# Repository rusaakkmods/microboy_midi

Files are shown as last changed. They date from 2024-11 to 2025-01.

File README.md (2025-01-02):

rusaaKKMODS - MicroBOY MIDI
---------------------------
'SPECIAL THANKS TO:'
  - Johan Kotlinski (@johan_kotlinski) for his work on LSDJ.
  - Timothy Lamb (@trash80) for his work on Arduinoboy. It's a great reference for me.
  - Nikita Bogdan (@nikitabogdan) & Alfian (instagram: @alfian_nay93) for briliant PC ideas!
  - AND of course our kooky AI: GPT 4o (ChatGPT, Copilot). Why not!!

 The code is still in the early stage, but it’s working as expected. The Gameboy is sending MIDI messages to the microcontroller, and the microcontroller is routing the messages to the MIDI output. 
 The next step is to add more features to the microcontroller, such as saving the configuration to EEPROM, adding a rotary encoder to change the output channel, and adding a button to change the CC mode and scaling.

  Reading Gameboy Message LSDJ MI.OUT MODE
  ----------------------------------------
  When LSDJ in MI.OUT mode; it is actually the Gameboy being Slave!!.
  In order for LSDJ send data byte, we have to send clock signal bit by bit. 
  Each clock signal send to the Gameboy will also trigger sending 1 bit of data out from Serial Out (SO) line.
  Read: docs/gb_clock.md
  Downside: LSDJ doesn't send Sequencer BPM clock information!

  This project is using Arduino Pro Micro / Leonardo
  --------------------------------------------------
  - I'll add compatibility for other microcontroller later on
  - Serial1 is used for MIDI communication
  - Serial is used for debugging purpose. disable it when not needed
  - CLOCK_PIN is used for Gameboy Clock -- Connect to Gameboy Serial Clock (SC) // it is full duplex may crash the Gameboy/LSDJ
  - SI_PIN is used for Message In (SI) -- Connect to Gameboy Serial Out (SO)
  - SO_PIN is used for Message Out (SO) -- Connect to Gameboy Serial In (SI)
  - By default, LSDJ use channel 1, 2, 3, 4 for each track respectively (PU1, PU2, WAV, NOI)
  
  Microboy Features
  -----------------
  - Sync with LSDJ MI.OUT Mode
  - Utilizing Program Change 127 (Gunshot) | LSDJ Y command FF to trigger Clock!
  - Adjustable Velocity knob
  - BPM calculation
  - Redirect each track to different MIDI channel
  - OLED Display information
  - Rotary Knob Control Setup

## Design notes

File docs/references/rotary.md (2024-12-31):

### Fixing Rotary Encoder Issues: References and Techniques

#### 1. Rotary Encoder Debouncing
**Reference:** [Debouncing Rotary Encoders](https://www.gammon.com.au/forum/?id=14175)

- This tutorial explains hardware and software debounce techniques for rotary encoders.
- Covers RC filters for hardware and software algorithms for filtering noisy transitions.

#### 2. Arduino Encoder Library
**Reference:** [Arduino Encoder Library (GitHub)](https://github.com/PaulStoffregen/Encoder)

- This library efficiently handles quadrature decoding for rotary encoders.
- Works well for both simple and high-speed encoders.
- Handles edge cases like skipped pulses due to fast rotation.

#### 3. Quadrature Decoding Explained
**Reference:** [How Rotary Encoders Work](https://www.pjrc.com/teensy/td_libs_Encoder.html)

- A detailed explanation of quadrature signals and how to decode them accurately.
- Includes information about state transitions and how to avoid invalid states.

#### 4. Noise Filtering Techniques
**Reference:** [Filtering Noisy Signals](https://www.allaboutcircuits.com/technical-articles/debouncing-switches-in-hardware-and-software/)

- Discusses noise filtering using hardware components (RC filters) and software logic.
- Provides insights into creating robust signal filters for noisy environments.

#### 5. Pin Change Interrupts (PCINT)
**Reference:** [Using Pin Change Interrupts](https://www.gammon.com.au/forum/?id=10896)

- Explains how to configure PCINT on AVR-based microcontrollers.
- Demonstrates efficient interrupt handling for signal changes.

### Techniques to Solve Similar Issues

#### 1. **Check Encoder Quality**
- Low-cost encoders may produce unstable signals. Use high-quality brands like **ALPS** or **Bourns** for better results.

#### 2. **State Machine for Quadrature Decoding**
- Implement a state machine to validate transitions and ignore invalid or noisy transitions.

#### 3. **Debounce Delay**
- Use a debounce delay of 5-10 ms depending on the encoder’s rotational speed.

#### 4. **Hardware Noise Filtering**
- Use an **RC filter** for each encoder signal line:
  - Resistor: 10 kΩ
  - Capacitor: 0.1 µF
- This reduces high-frequency noise.

#### 5. **Timer-Based Polling**
- Instead of relying solely on interrupts, use a timer to poll encoder states at a fixed frequency (e.g., every 1 ms).

#### 6. **Oscilloscope Analysis**
- Use an oscilloscope to analyze the encoder signals for noise or irregularities.

#### 7. **Use Encoder Libraries**
- Libraries like `Encoder.h` simplify decoding logic and optimize performance for high-speed rotations.

#### 8. **Combine Hardware and Software Filters**
- Use a combination of hardware (RC filter) and software debounce or noise filtering algorithms.

#### 9. **Optimize ISR**
- Ensure the Interrupt Service Routine (ISR) is short and efficient. Delegate heavy processing to the main loop.

### Example Solution with Encoder Library and PCINT
- Use the **Encoder** library for accurate quadrature decoding.
- Enable PCINT for additional functionality like buttons or other input monitoring.

#### Sample Code:
```cpp
#include <Encoder.h>
#include <avr/interrupt.h>

// Pin definitions
#define ENCODER_PIN_A 8
#define ENCODER_PIN_B 9
#define BUTTON_PIN 7

Encoder myEnc(ENCODER_PIN_A, ENCODER_PIN_B);
volatile bool buttonPressed = false;

ISR(PCINT0_vect) {
  if (digitalRead(BUTTON_PIN) == LOW) {
    buttonPressed = true;
  } else {
    buttonPressed = false;
  }
}

void setup() {
  pinMode(ENCODER_PIN_A, INPUT_PULLUP);
  pinMode(ENCODER_PIN_B, INPUT_PULLUP);
  pinMode(BUTTON_PIN, INPUT_PULLUP);

  PCICR |= (1 << PCIE0); // Enable PCINT for group 0
  PCMSK0 |= (1 << PCINT7); // Enable PCINT for BUTTON_PIN
  sei(); // Enable global interrupts
}

void loop() {
  long position = myEnc.read();
  if (buttonPressed) {
    // Handle button press
  }
  // Handle encoder position changes
}
```

By following these references and implementing the suggested techniques, you can fix most issues with rotary encoder noise, missed steps, and jitter.

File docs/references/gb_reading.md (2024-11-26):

### Improving Game Boy DMG Link Transmission

Improving the **Game Boy DMG** link transmission stability can help ensure more reliable data exchange, especially if you're experiencing **noise**, **missed bits**, or **unsynchronized communication**. Here are several strategies to improve the quality and reliability of the **link transmission** between Game Boy DMG units or between a Game Boy and another device like an Arduino:

#### 1. Use Pull-Up Resistors and Debouncing Capacitors
- The **Serial In (SI)** and **Serial Out (SO)** lines should be pulled **HIGH** by default to avoid floating, which can lead to **noise** and incorrect data readings.
- Adding **external pull-up resistors** of about **10kΩ** to **5V** on both the **SI** and **SO** pins can help keep the lines stable when no active data is being transmitted. To do this:

- Connect one end of a **10kΩ resistor** to **5V**.
- Connect the other end to the **SI** or **SO** line.
- Repeat this for both the **SI** and **SO** pins to ensure they are pulled HIGH when idle.

This will help stabilize the communication lines and avoid floating states.
- Even if internal pull-ups are used, adding **external pull-ups** may help ensure stronger and more consistent signal levels.

#### 2. Reduce Cable Length and Use Shielded Cables
- **Long cables** can lead to **signal degradation** and **cross-talk**, which can increase the likelihood of errors in the transmission.
- **Shorten the link cable** as much as possible, or use a cable with **shielded wiring** to minimize **electrical interference**.
- If the Game Boy link cable is being extended, ensure it’s done with properly shielded wires to avoid picking up **EMI (Electromagnetic Interference)**.

#### 3. Improve Clock Signal Quality
- The **Serial Clock (SC)** signal quality is crucial to ensure both the **master** and **slave** Game Boys stay synchronized.
- Ensure that the clock signal generated by the master is clean, with no **jitter** or **glitches**.
- To achieve this:
  - **Use capacitors** (e.g., **100 nF** ceramic capacitors) between the **SC line** and **ground** to filter out high-frequency noise.
  - If you are generating the clock from an Arduino or other microcontroller, experiment with adjusting the **timing** (e.g., slightly increasing or decreasing the delays) to find the most stable transmission speed.

#### 4. Stabilize Power Supply
- A **stable power supply** is essential for reliable communication.
- Ensure that your Game Boy DMG is powered by **fresh batteries** or a reliable **regulated power supply**.
- If using batteries, **fresh alkaline batteries** are better for maintaining consistent voltage. Rechargeable batteries can sometimes introduce **voltage drops** that may lead to communication errors.

#### 5. Debounce the Clock and Data Lines with Capacitors
- Electrical noise or bouncing signals can cause erroneous triggering of the data lines.
- **Debouncing** the **clock and data lines** can be achieved by:

- **Adding capacitors**: Connect a **small ceramic capacitor** (e.g., **10 nF to 100 nF**) between each data line (**SI** and **SO**) and **ground**. This helps filter out any spikes or noise on these lines and stabilizes the signal.
  - For the **clock line (SC)**, add a **100 nF capacitor** between the clock line and ground to reduce jitter and noise.
  - Ensure the capacitors are physically close to the Game Boy link port to minimize interference.
  - Adding a **small capacitor** (e.g., **10 nF to 100 nF**) between the clock line and ground to filter out any spikes or noise.
  - In software, adding a **small delay** after each clock pulse can help stabilize the signal.

#### 6. Minimize Crosstalk Between Lines
- In the **Game Boy link cable**, **crosstalk** between the **clock**, **SI**, and **SO** lines can introduce unwanted signals.
- Keeping the **clock line** separate from the **data lines** in the cable can help reduce crosstalk.
- Use **twisted pair wiring** for data and ground, and a separate shielded wire for the clock line.

#### 7. Proper Grounding
- Ensure that both Game Boys share a **common ground** through the link cable.
- A poor or inconsistent ground connection can lead to differences in voltage levels between the devices, resulting in errors.
- Verify that all ground connections in the link cable are properly connected and that there is minimal resistance between them.

#### 8. Check for Consistent Timing
- The **master Game Boy** controls the pace of data transfer through the **clock pulses**.
- Ensure that the **clock timing** is consistent, especially if using a custom device (e.g., Arduino) to generate the clock.
- Use an **oscilloscope** to monitor the clock and data signals:
  - Check that the **clock pulse width** is consistent.
  - Verify that each bit is being read correctly by the master in sync with the clock transitions.

#### 9. Adjust Master Clock Speed
- The typical **link clock speed** for the Game Boy DMG is **8 kHz**, but small variations may help in improving reliability.
- Experiment with slightly different clock frequencies (e.g., **7.5 kHz to 8.5 kHz**) to find the most stable communication speed for your specific hardware.

#### 10. Improve Data Protocol Handling in Software
- The Game Boy link transmission depends heavily on the **game software** for handling data correctly.
- Ensure that your code is capable of:
  - **Retrying data transmission** if an error is detected.
  - Using **handshaking** techniques to ensure both devices are ready for communication.
- Some games use a **checksum** or other verification mechanism to validate data integrity. Implementing similar methods can help detect and correct errors.

### Key Adjustments:
- **Pull-Up Resistors**: Use **`INPUT_PULLUP`** to keep the **SI** and **SO** pins stable.
- **Delays**: Carefully adjusted **delayMicroseconds()** values to stabilize the clock and data lines.

By addressing these hardware and timing factors, you can significantly improve the reliability of the Game Boy DMG link communication and reduce the likelihood of errors during data transmission.

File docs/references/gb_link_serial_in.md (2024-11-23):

### Should the Slave's Serial In (SI) Pin Be HIGH by Default?

Yes, the **slave's Serial In (SI)** pin should be **HIGH by default**. This is a common requirement for **synchronous serial communication** in the Game Boy link protocol. Here's why:

#### Why the Serial In (SI) Pin Should Be HIGH by Default

1. **Idle State Requirement**:
   - In the Game Boy link communication protocol, the **Serial In (SI)** pin, which is used by the **slave** to receive data, is typically set to **HIGH** during the **idle state**.
   - This idle HIGH state ensures that there is no unintended signal or noise interpreted as valid data when the link is not actively being used.

2. **Avoiding False Triggers**:
   - If the **SI** line were **floating** or left **LOW** by default, noise could be interpreted as incoming bits, which would lead to incorrect data being received or communication errors.
   - Pulling the **SI** line HIGH ensures that any actual communication starts with a clear signal when the **master** sends data.

3. **Pull-Up Resistors**:
   - To ensure that the **SI** line is HIGH by default, a **pull-up resistor** is used. In the Game Boy hardware and typical link cable circuits, there may be internal or external pull-up resistors on the **SI** line.
   - In a setup involving an Arduino or another microcontroller, you can enable an **internal pull-up resistor** to ensure the **SI** pin stays HIGH unless actively driven LOW by the master.

4. **Consistent Communication**:
   - The Game Boy link protocol expects consistent signal levels. Having the **SI** line HIGH by default helps both the **master** and **slave** remain synchronized, and ensures that the **slave** only reacts to deliberate signals from the master.

#### How to Set the SI Pin HIGH by Default

If you're using an Arduino to simulate the **master** or **slave** in the link communication, you can set the **SI** pin HIGH by enabling an internal pull-up resistor:

```cpp
pinMode(SI_PIN, INPUT_PULLUP);
```

- **`INPUT_PULLUP`** mode will connect an internal **pull-up resistor** to the **SI** pin, ensuring it stays **HIGH** unless pulled LOW by the master device.

#### Summary
- The **slave's Serial In (SI)** pin should be **HIGH** by default when idle.
- This is achieved by using a **pull-up resistor** to avoid noise or unintended signals that could be misinterpreted.
- Setting the **SI** line HIGH by default ensures clean and reliable communication, which is critical for the **synchronous** Game Boy link protocol.

This default HIGH state helps maintain stability in the communication protocol, allowing both devices to recognize valid data transmission more effectively.

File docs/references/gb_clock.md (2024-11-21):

### Game Boy Clock Rate Explained

The **Game Boy clock rate** refers to the frequency of the **Serial Clock (SC)** signal on the Game Boy link port, which is used to synchronize data transfer between two devices (e.g., two Game Boys or a Game Boy and another device).

#### Game Boy Serial Clock Rate

1. **Purpose of Serial Clock (SC)**:
   - The **Serial Clock (SC)** is a signal generated by the **master device** (usually one Game Boy in the link setup).
   - It synchronizes the transfer of data bits between the devices connected via the link port.

2. **Clock Frequency**:
   - The clock operates at approximately **8 KHz** (8000 cycles per second).
   - This means each clock pulse lasts around **125 microseconds** (1 / 8000 = 0.000125 seconds).

3. **Data Rate**:
   - The data is transferred **synchronously** with the clock, meaning that:
     - 1 bit is sent per clock cycle.
     - The **bit rate** is the same as the clock frequency: **8 Kbps (kilobits per second)**.
   - Since data is transmitted in bytes (8 bits), the effective **byte rate** is approximately:
     - **1000 bytes per second** (8000 bits ÷ 8 = 1000 bytes).

#### Timing of Clock Pulses

1. **Idle State**:
   - When the link port is not actively transmitting data, the clock signal remains **LOW**.

2. **Active Transmission**:
   - During communication, the clock signal toggles between **LOW** and **HIGH** states.
   - Each rising edge of the clock signals the devices to read or write a bit of data.

3. **Duration of Each Clock Pulse**:
   - The clock pulse consists of two parts:
     - **LOW period**: ~62.5 microseconds.
     - **HIGH period**: ~62.5 microseconds.

#### Clock Role in Synchronous Communication

1. **Master/Slave Role**:
   - In a typical Game Boy link connection:
     - The **master Game Boy** generates the clock signal.
     - The **slave device** reads the clock to synchronize data transfer.
   - This ensures that both devices exchange data in lockstep, without needing independent timing mechanisms.

2. **Slave Role in Receiving Master Clock**:
   - The **slave Game Boy** uses the clock signal from the master to determine exactly when to sample incoming bits from the **Serial Out (SO)** pin and when to send bits via the **Serial In (SI)** pin.
   - On each rising edge of the clock signal, the slave reads the current bit from the **SO** line or writes a bit to the **SI** line.
   - The **slave** does not generate its own clock signal but fully relies on the master's clock to maintain synchronization, ensuring that data is transferred reliably without discrepancies in timing.
   - This dependency on the master clock ensures that the slave is always synchronized with the master, preventing any mismatch in the data sent and received. The slave device essentially "waits" for each clock pulse from the master before performing any data read or write operations, ensuring a consistent and orderly data flow.

3. **Data Transmission**:
   - Data is exchanged bit-by-bit on each clock pulse.
   - The **Serial Out (SO)** pin sends data out from one Game Boy, while the **Serial In (SI)** pin receives data from the other device.
   - The clock ensures the bits are sampled and latched at the correct time.

#### Real-World Example of Clock Rate

1. **In Pokémon Red/Blue**:
   - During a Pokémon trade, the **master Game Boy** generates the clock to synchronize the exchange of Pokémon data.
   - Data packets are sent bit-by-bit, with each bit aligned to the clock signal.

2. **In Tetris**:
   - The clock signal is used to synchronize the game state between the two Game Boys, ensuring real-time updates.

#### How to Measure the Clock Rate

To measure the **Game Boy clock rate**:

1. **Use an Oscilloscope**:
   - Connect the probe to the **Serial Clock (SC)** pin on the Game Boy link port.
   - Measure the frequency of the clock pulses.

2. **Use an Arduino**:
   - You can write an Arduino sketch to measure the duration of HIGH and LOW periods on the SC pin and calculate the frequency:
     
     ```cpp
     void setup() {
       pinMode(9, INPUT); // Connect SC to Pin 9
       Serial.begin(9600);
     }

     void loop() {
       unsigned long highTime = pulseIn(9, HIGH);
       unsigned long lowTime = pulseIn(9, LOW);
       unsigned long period = highTime + lowTime;
       if (period > 0) {
         float frequency = 1000000.0 / period; // Frequency in Hz
         Serial.print("Frequency: ");
         Serial.print(frequency);
         Serial.println(" Hz");
       }
       delay(1000);
     }
     ```

#### Summary
- The **Game Boy clock rate** is around **8 KHz**, corresponding to a **bit rate** of **8 Kbps** and a **byte rate** of **1000 bytes per second**.
- The clock signal synchronizes the transfer of data between devices, ensuring accurate and reliable communication.

/*
The Game Boy link cable operates at a relatively low speed compared to modern communication standards. 
The Game Boy's serial communication operates at approximately 8,192 bits per second (bps), 
which translates to a bit period of about 122 microseconds.

Normal Latency in Game Boy Link Communication
Bit Period: Approximately 122 microseconds per bit.
Byte Transmission Time: Since a byte consists of 8 bits, 
the transmission time for one byte is approximately ( 8 \times 122 \text{ microseconds} = 976 \text{ microseconds} ).
Ensuring Reliable Communication
To ensure reliable communication with the Game Boy, you need to synchronize your microcontroller's timing with the Game Boy's clock. 
This involves carefully managing the delays in your code.
*/

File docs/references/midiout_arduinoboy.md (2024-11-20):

Each of the 4 gameboy channels send MIDI data on 4 midi channels by the use of effects commands:

* `Nxx` - Sends a MIDI Note - Absolute to the value placed in the effect. N00 sends note off, `N01`-`N6F` send midi notes 1 to 112.
* `Qxx` - Sends a [MIDI Note](http://www.electronics.dit.ie/staff/tscarff/Music_technology/midi/midi_note_numbers_for_octaves.htm) relative to the current channel's pitch. The effect value is a offset. so `Q0C` in `PU1` would send a note 1 octave higher than what `PU1` is currently playing. This is useful as a table command to track midi notes as normal notes in the sequencer.
* `Xxx` - Sends a MIDI CC - By default in Arduinoboy the high nibble selects a CC#, and the low nibble sends a value `0-F` to `0-127`. This can be changed to allow just 1 midi CC with a range of `00`-`6F`, or 7 CCs with scaled or unscaled values.
* `Yxx` - Sends a program/patch/preset change.

By default each channel of LSDJ is mapped to midi channels 1-4. For example note commands from PU1 will be sent to midi channel 1.

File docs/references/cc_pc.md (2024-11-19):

**MIDI Control Change (CC)**

In MIDI (Musical Instrument Digital Interface), **Control Change (CC)** is a type of message used to convey specific real-time changes in a musical performance. It is often used to modify parameters like volume, pan, modulation, effects, and many others, allowing a musician to have expressive control over the sound.

### **Details of Control Change (CC):**
- **Message Structure**: Control Change messages consist of three bytes:
  1. **Status Byte**: Indicates that the message is a Control Change, followed by the MIDI channel number (0–15).
  2. **Controller Number Byte**: Identifies which control is being affected. This number ranges from **0 to 127**, and each number represents a specific control, such as modulation wheel (CC 1), sustain pedal (CC 64), etc.
  3. **Controller Value Byte**: Represents the value for that controller, ranging from **0 to 127**. For example, with a volume control, a value of 0 would mean no sound, while 127 would mean full volume.

- **Typical Control Change Uses**:
  - **CC 1 (Modulation Wheel)**: Controls modulation, often used to add vibrato or other effects.
  - **CC 7 (Channel Volume)**: Controls the main volume of a MIDI channel.
  - **CC 10 (Pan)**: Adjusts the stereo position of the sound.
  - **CC 64 (Sustain Pedal)**: Acts as a sustain pedal on a piano—values 0 to 63 are "off", and 64 to 127 are "on".

- **Range**: The **controller number** (0–127) is mapped to various controls, and the **value** (0–127) represents the intensity or state of that control.

- **Real-Time Interaction**: Control Change messages are typically used for **real-time** interaction with the synthesizer or instrument. For example, moving a modulation wheel while playing would send a series of Control Change messages that modify the sound in real time.

- **MIDI Learn**: Many software instruments and DAWs support a feature called **MIDI Learn**, where you can map a physical MIDI controller knob or fader to any virtual parameter using a Control Change message.

- **Common CC Numbers**:
  - **CC 0**: Bank Select (MSB)
  - **CC 1**: Modulation Wheel
  - **CC 7**: Channel Volume
  - **CC 10**: Pan
  - **CC 11**: Expression Controller
  - **CC 64**: Sustain Pedal (Hold Pedal)
  - **CC 120–127**: Channel Mode Messages (like "All Sound Off" or "Reset All Controllers")

Control Change messages are crucial for making electronic music dynamic and expressive, as they allow a performer to tweak many aspects of a sound or performance in real time.

---

**MIDI Program Change (PC)**

A **Program Change** (often called **Patch Change**) is a type of MIDI message used to change the **instrument sound** or **preset** on a synthesizer, sound module, or any other MIDI-compatible device. This allows musicians to quickly switch between different sounds, such as piano, strings, guitar, or any other patches, during a performance.

### **Details of Program Change:**
- **Message Structure**: A Program Change message consists of two bytes:
  1. **Status Byte**: Indicates that the message is a Program Change and also includes the **MIDI channel** number (0-15).
  2. **Program Number Byte**: Identifies the **program (preset)** to be selected. This number ranges from **0 to 127**, representing the preset number on the synthesizer or device.

- **Use in Performances**: During live performances or recording sessions, a musician can send Program Change messages to seamlessly switch between different sounds without having to manually adjust settings on the hardware or software. For example, in a sequence, you might switch from a **piano sound (Program 0)** to a **guitar sound (Program 24)** with a Program Change message.

- **Program Numbers**: Program numbers vary from 0 to 127, and the specific mapping of numbers to sounds depends on the synthesizer or General MIDI specification. General MIDI defines a standard set of 128 instruments, such as:
  - **0**: Acoustic Grand Piano
  - **24**: Nylon Guitar
  - **40**: Violin
  - **73**: Flute
  - **127**: Gunshot

  However, in many modern synths or devices, the specific sound might not adhere to the General MIDI standard, and manufacturers often use custom sound banks.

- **Bank Select**: Some synthesizers or devices have more than 128 sounds. In these cases, **Bank Select** messages (Control Change **CC 0** and **CC 32**) are used in combination with Program Change messages to switch between different banks of programs. Essentially, the Bank Select defines which set of 128 sounds you are switching among, and the Program Change then selects the specific sound from that bank.

- **Example Use Case**:
  - If a keyboard player wants to switch from a **piano sound** to a **synth pad** while playing, they can send a Program Change message to the keyboard. This switch can be triggered via a MIDI controller, foot pedal, or even be embedded in a sequencer track.

### **Summary:**
- A **Program Change** message is a simple and powerful way to select different instrument presets or patches.
- It typically consists of a **status byte** and a **program number byte**.
- The value of the program number is **0-127**, selecting from the available presets in the device.
- It is often combined with **Bank Select** to access more than 128 sounds on advanced synthesizers.

Program Change messages are fundamental in MIDI for creating dynamic, expressive, and diverse musical performances and arrangements, allowing musicians to instantly switch between different timbres and sounds during a piece.

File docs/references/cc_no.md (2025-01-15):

**Full List of MIDI Control Change Numbers (CC)**

Below is a full list of the **MIDI Control Change (CC) Numbers**, which are used to control various parameters of a MIDI-compatible instrument or device. Each control number ranges from **0 to 127** and corresponds to a specific function.

### **Standard MIDI Control Change Numbers**
// default arduinoboy use {1,2,3,7,10,11,12}

| CC Number  | Function |
|---|---|
| 0 | Bank Select (MSB) |
| 1 | Modulation Wheel |
| 2 | Breath Controller |
| 3 | Undefined |
| 4 | Foot Controller |
| 5 | Portamento Time |
| 6 | Data Entry (MSB) |
| 7 | Channel Volume |
| 8 | Balance |
| 9 | Undefined |
| 10 | Pan |
| 11 | Expression Controller |
| 12 | Effect Control 1 |
| 13 | Effect Control 2 |
| 14 | Undefined |
| 15 | Undefined |
| 16 | General Purpose Controller 1 |
| 17 | General Purpose Controller 2 |
| 18 | General Purpose Controller 3 |
| 19 | General Purpose Controller 4 |
| 20-31 | Undefined |
| 32 | Bank Select (LSB) |
| 33 | Modulation Wheel (LSB) |
| 34 | Breath Controller (LSB) |
| 35 | Foot Controller (LSB) |
| 36 | Portamento Time (LSB) |
| 37 | Data Entry (LSB) |
| 38 | Channel Volume (LSB) |
| 39 | Balance (LSB) |
| 40-63 | Undefined |
| 64 | Sustain Pedal (Hold Pedal) |
| 65 | Portamento On/Off |
| 66 | Sostenuto |
| 67 | Soft Pedal |
| 68 | Legato Footswitch |
| 69 | Hold 2 |
| 70 | Sound Controller 1 (Sound Variation) |
| 71 | Sound Controller 2 (Timbre/Harmonic Intensity) |
| 72 | Sound Controller 3 (Release Time) |
| 73 | Sound Controller 4 (Attack Time) |
| 74 | Sound Controller 5 (Brightness) |
| 75-79 | Sound Controllers 6-10 |
| 80 | General Purpose Controller 5 |
| 81 | General Purpose Controller 6 |
| 82 | General Purpose Controller 7 |
| 83 | General Purpose Controller 8 |
| 84 | Portamento Control |
| 85-90 | Undefined |
| 91 | Effects 1 Depth (Reverb Send Level) |
| 92 | Effects 2 Depth (Tremolo Depth) |
| 93 | Effects 3 Depth (Chorus Send Level) |
| 94 | Effects 4 Depth (Detune Depth) |
| 95 | Effects 5 Depth (Phaser Depth) |
| 96 | Data Increment |
| 97 | Data Decrement |
| 98 | Non-Registered Parameter Number (LSB) |
| 99 | Non-Registered Parameter Number (MSB) |
| 100 | Registered Parameter Number (LSB) |
| 101 | Registered Parameter Number (MSB) |
| 102-119 | Undefined |
| 120 | All Sound Off |
| 121 | Reset All Controllers |
| 122 | Local Control On/Off |
| 123 | All Notes Off |
| 124 | Omni Mode Off |
| 125 | Omni Mode On |
| 126 | Mono Mode On (Poly Off) |
| 127 | Poly Mode On (Mono Off) |

### **Summary**
MIDI Control Change messages use control numbers ranging from **0 to 127** to manipulate various parameters of a synthesizer or MIDI device, from sound modulation to volume control. Understanding these CC numbers is essential for making electronic music expressive and dynamic.

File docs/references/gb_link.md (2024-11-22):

### Game Boy Bit Transmission Speed

The **Game Boy** can send bits over its link port at a rate of approximately **8 Kbps** (kilobits per second). This bit rate is directly related to the **Serial Clock (SC)** signal generated during communication.

#### Key Factors of Game Boy Bit Transmission Speed

1. **Serial Clock Frequency**:
   - The **clock signal (SC)** generated by the **master device** (usually one of the Game Boys in a link connection) controls the speed of data transfer.
   - The clock frequency is approximately **8 kHz**, which means the **bit rate** is also **8 Kbps**.

2. **Synchronous Communication**:
   - The Game Boy link communication is **synchronous**, meaning that each clock pulse corresponds to the transmission of **1 bit** of data.
   - With a clock frequency of **8 kHz**, one bit is transferred every **125 microseconds** (1 / 8000 seconds).

3. **Data Rate Calculation**:
   - The **bit rate** is **8 Kbps** (8,000 bits per second).
   - Since data is transferred in **bytes** (8 bits per byte), the effective **byte rate** is:
     - **1000 bytes per second** (8,000 bits per second divided by 8 bits per byte).

#### Factors Affecting Transmission Speed

1. **Clock Signal Stability**:
   - The **master clock** determines the exact rate at which bits are transmitted.
   - A stable clock is critical to ensure the **slave device** can synchronize correctly with the data being sent.

2. **Hardware Limitations**:
   - The original **Game Boy (DMG)** and later models like **Game Boy Color** were designed with this clock frequency as a compromise between power consumption and effective communication speed.
   - The **link port** was intended primarily for simple multiplayer gameplay, trading, and basic data synchronization, so **8 Kbps** was considered sufficient.

3. **Impact of Custom Clock Generation**:
   - If you are using a device like an **Arduino** to generate a master clock for the Game Boy, the precision of your clock signal will impact how reliably the Game Boy can transmit and receive data.
   - If the clock deviates significantly from **8 kHz**, communication issues may arise, such as missed bits or incorrect synchronization.

#### Practical Communication Example

- **Pokémon Trading**:
  - In games like **Pokémon Red/Blue**, data is exchanged bit-by-bit using the **8 Kbps** link rate.
  - Each byte of data takes **8 clock cycles** to send, and the **master Game Boy** uses the clock to synchronize the data transfer.

- **Tetris Multiplayer**:
  - For fast-paced multiplayer games like **Tetris**, the **8 Kbps** link rate is sufficient to keep both players' game states synchronized in real-time.

#### Potential Enhancements or Limitations

- **Higher Clock Rates**:
  - The original hardware design of the Game Boy and its link port limits the maximum clock rate to **8 kHz**.
  - Trying to increase the clock rate significantly might lead to instability or data corruption, as the Game Boy hardware wasn't designed to handle faster speeds.

- **Lower Clock Rates**:
  - The clock rate can be reduced (for instance, during emulation or custom hardware setups), but this would make data transfer slower and might not be suitable for real-time gameplay.

#### Summary
- The **Game Boy link port** operates at a bit rate of approximately **8 Kbps**.
- This means the **clock frequency** is around **8 kHz**, allowing a **byte rate** of **1000 bytes per second**.
- The **speed** is adequate for its intended applications, such as multiplayer gameplay and data exchange in games like **Pokémon**.

If you are using an **Arduino** to generate a master clock, ensuring the clock runs at **8 kHz** consistently is key to reliable communication.

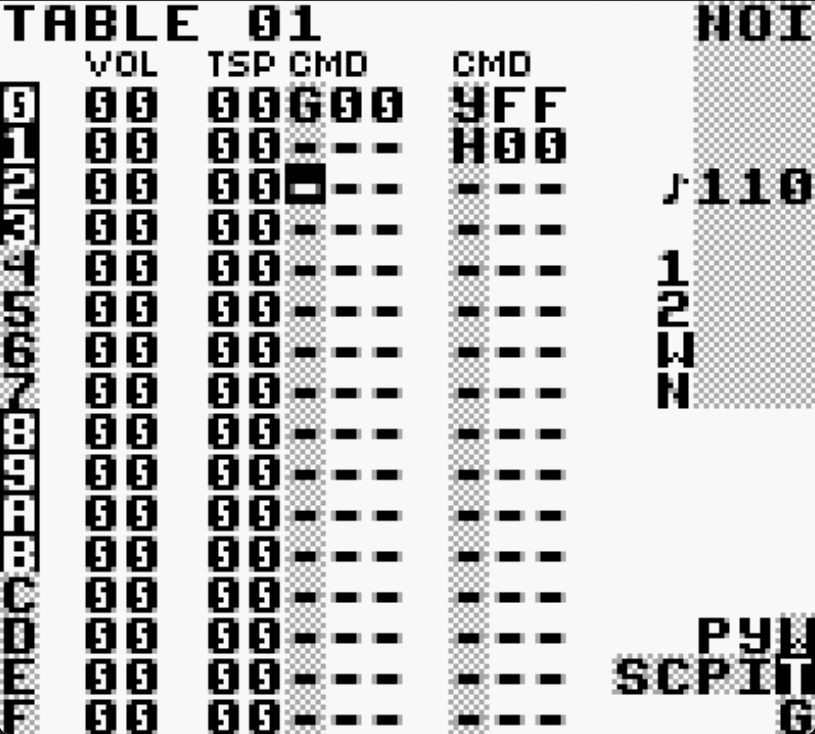
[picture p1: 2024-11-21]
docs/images/normal.png

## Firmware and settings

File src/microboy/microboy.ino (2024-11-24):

#include <MIDIUSB.h>
#include <Wire.h>
#include <Adafruit_GFX.h>
#include <Adafruit_SSD1306.h>
#include <limits.h>

#define PRODUCT_NAME "MicroBOY MIDI"
#define VERSION "v0.0.1"
#define RUSAAKKMODS "rusaaKKMODS @ 2024"

// #define DEBUG_MODE

// #define USE_MIDI_h  // comment this line if you want to use USB MIDI

#ifdef USE_MIDI_h
#include <MIDI.h>
MIDI_CREATE_INSTANCE(HardwareSerial, Serial1, MIDI);
#else
HardwareSerial &MIDI = Serial1;
#endif

// RESERVERD PINS
// #define OLED_SDA SDA
// #define OLED_SCL SCL
#define CLOCK_PIN A0 // to be connected to Gameboy Clock
#define SO_PIN A1    // to be connected to Gameboy Serial In
#define SI_PIN A2    // to be connected to Gameboy Serial Out

// rotary encoder for control and settings
#define ROTARY_CLK 9
#define ROTARY_DT 8
#define ROTARY_SW 7

// tweak these value to get better stability
#define BIT_DELAY 1
#define BYTE_DELAY 4000
#define MIDI_DELAY 20000

// OLED display
#define SCREEN_WIDTH 128
#define SCREEN_HEIGHT 32
#define OLED_I2C_ADDRESS 0x3C

Adafruit_SSD1306 display(SCREEN_WIDTH, SCREEN_HEIGHT, &Wire, -1);

byte outputChannel[4] = {1, 2, 3, 4};         // default channel 1, 2, 3, 4 //TODO: controlable by rotary encoder and save in EEPROM
bool ccMode[4] = {true, true, true, true};    // default CC mode 1, 1, 1, 1 //TODO: should be configurable maybe save in EEPROM
bool ccScaling[4] = {true, true, true, true}; // default scaling 1, 1, 1, 1 //TODO: should be configurable maybe save in EEPROM
byte ccNumbers[4][7] = {
    {1, 2, 3, 7, 10, 11, 12},
    {1, 2, 3, 7, 10, 11, 12},
    {1, 2, 3, 7, 10, 11, 12},
    {1, 2, 3, 7, 10, 11, 12}}; // default CC numbers 1, 2, 3, 7, 10, 11, 12 //TODO: should be configurable maybe save in EEPROM

// enable these features, caution! it is GLITCHY!!
bool pcEnabled = false;
bool ccEnabled = false;
bool realTimeEnabled = false;

// Clocking
uint64_t lastTapTime = 0;
volatile float interval = 0.00;
uint64_t nextClockTime = 0;
float bpm = 0.00;
uint8_t ticking = 0;
uint8_t tickBuffer = 0.01;

// Gameboy Serial Communication
uint64_t lastReadGameboy = 0;
bool isCommandWaiting = false;
byte commandWaiting = 0x00;
byte experimentalCorrection = 0x00;

// track 0-PU1, 1-PU2, 2-WAV, 3-NOI
volatile byte lastNote[4] = {0, 0, 0, 0};
volatile int velocity = 127; // adjustable Global Velocity, affecting all channels
volatile byte lastTrack = 0; // Track with the shortest update interval

// control interface
byte switchControlState;
bool lastControlState = HIGH;
bool controlPressed = false;
uint64_t lastPrint = 0;

void sendMIDI(midiEventPacket_t message)
{
  MidiUSB.sendMIDI(message);
  MidiUSB.flush();

#ifndef USE_MIDI_h
  Serial1.write(message.byte1);
  Serial1.write(message.byte2);
  Serial1.write(message.byte3);
  Serial1.flush();
#endif
}

void noteOn(byte track, byte note)
{
  noteStop(track); // stop previous note consider each track is monophonics
  // send to USB MIDI
  midiEventPacket_t message = {0x09, 0x90 | outputChannel[track] - 1, note, velocity};
  sendMIDI(message);

#ifdef USE_MIDI_h
  MIDI.sendNoteOn(note, velocity, outputChannel[track]);
  Serial1.flush();
#endif

  lastNote[track] = note;
}

void noteStop(byte track)
{
  byte note = lastNote[track];
  if (note)
  {
    // send to USB MIDI
    midiEventPacket_t message = {0x08, 0x80 | outputChannel[track] - 1, note, 0x00};
    sendMIDI(message);

#ifdef USE_MIDI_h
    MIDI.sendNoteOff(note, 0x00, outputChannel[track]);
    Serial1.flush();
#endif

    lastNote[track] = 0;
  }
}

void noteStopAll()
{
  for (uint8_t track = 0; track < 4; track++)
  {
    noteStop(track);
  }
}

void sendNote(byte track, byte note)
{
  if (note)
  { // value > 0 then its a "Note On" 1-127 | LSDJ note range 0-119
    noteOn(track, note);
  }
  else
  { // value 0 then its a "Note Off"
    noteStop(track);
  }
}

void clockReset()
{
  ticking = 0;
  lastTapTime = 0;
  interval = 0;
  bpm = 0;
  nextClockTime = 0;
}

void clockMIDI()
{ // its clocking time!!
  if (bpm > 0)
  {
    unsigned long currentTime = micros();
    if (currentTime >= nextClockTime)
    {
      midiEventPacket_t message = {0x0F, 0xF8, 0x00}; // MIDI Clock
      sendMIDI(message);

#ifdef USE_MIDI_h
      MIDI.sendRealTime(midi::Clock);
      Serial1.flush();
#endif

      // float bufferedInterval = interval * (1 - tickBuffer); //buffer: to make sure executed well
      // Calculate the tick interval based on the current BPM
      // unsigned long tickInterval = 60000000 / (bpm * 24);

      nextClockTime = currentTime + interval;
    }
  }
}

void clockTap()
{
  unsigned long currentTime = micros();

  if (lastTapTime > 0) // skip on first tap
  {
    uint64_t currentInterval = round((currentTime - lastTapTime) / 6);
    interval = currentInterval;

    bpm = round((60000000.0 / (interval * 24)) / 5) * 5;
  }
  else
  {
    // kicked off starter!!!
    bpm = 120;
    interval = 20833.33;
  }
  lastTapTime = currentTime;

  // bpm = 120;
  // interval = 20833.33;
}

/* Reference from Arduinoboy (https://github.com/trash80/Arduinoboy)
// by Timothy Lamb @trash80
// ------------------------------------
// X## - Sends a MIDI CC -
// By default in Arduinoboy the high nibble selects a CC#, and the low nibble sends a value 0-F to 0-127.
// This can be changed to allow just 1 midi CC with a range of 00-6F, or 7 CCs with scaled or unscaled values.
//
// CC Mode:
// default: 1 for all 4 tracks
// - 0: use 1 midi CC, with the range of 00-6F,
// - 1: uses 7 midi CCs with the range of 0-F (the command's first digit would be the CC#)
// either way the value is scaled to 0-127 on output
// ------------------------------------
// CC Scaling:
// default: 1 for all 4 tracks
// - 1: scales the CC value range to 0-127 as oppose to lsdj's incomming 00-6F (0-112) or 0-F (0-15)
// - 0: no scaling, the value is directly sent to midi out 0-112 or 0-15
// scaling in c:
// byte scaledValue = map(value, 0, 112, 0, 127); // 0-112 to 0-127
// byte scaledValue = map(value, 0, 15, 0, 127); // 0-112 to 0-127
// ------------------------------------
// CC Message Numbers
// default options: {1,2,3,7,10,11,12} for each track, these options are CC numbers for lsdj midi out
// If CC Mode is 1, all 7 ccs options are used per channel at the cost of a limited resolution of 0-F
*/
void sendControlChange(byte track, byte value)
{
  byte ccNumber;
  byte ccValue;

  if (ccMode[track])
  {
    if (ccScaling[track])
    {
      // CC Mode 1 with scaling
      ccNumber = ccNumbers[track][(value & 0xF0) >> 4]; // High nibble
      ccValue = map(value & 0x0F, 0, 15, 0, 127);       // Low nibble
    }
    else
    {
      // CC Mode 1 without scaling
      ccNumber = ccNumbers[track][(value & 0xF0) >> 4]; // High nibble
      ccValue = value & 0x0F;                           // Low nibble
    }
  }
  else
  {
    if (ccScaling[track])
    {
      // CC Mode 0 with scaling
      ccNumber = ccNumbers[track][0];       // Use the first CC number for Mode 0
      ccValue = map(value, 0, 112, 0, 127); // Scale the value
    }
    else
    {
      // CC Mode 0 without scaling
      ccNumber = ccNumbers[track][0]; // Use the first CC number for Mode 0
      ccValue = value;                // Direct value
    }
  }

  // send to USB MIDI
  midiEventPacket_t message = {0xB0 | outputChannel[track] - 1, ccNumber, ccValue};
  sendMIDI(message);

#ifdef USE_MIDI_h
  MIDI.sendControlChange(ccNumber, ccValue, outputChannel[track]);
  Serial1.flush();
#endif

#ifdef DEBUG_MODE
  Serial.print("CC Command - track:");
  Serial.print(track);
  Serial.print(" value:");
  Serial.println(value);
#endif
}

void sendProgramChange(byte track, byte value)
{
  // send to USB MIDI
  midiEventPacket_t message = {0xC0 | outputChannel[track] - 1, value, 0x00};
  sendMIDI(message);

#ifdef USE_MIDI_h
  MIDI.sendProgramChange(value, outputChannel[track]);
  Serial1.flush();
#endif
#ifdef DEBUG_MODE
  Serial.print("PC Command - track:");
  Serial.print(track);
  Serial.print(" value:");
  Serial.println(value);
#endif
}

void routeMessage(byte message, byte value)
{
  byte command = message - 0x70;
  byte track = 0;
  if (command < 0x04)
  { // 0-3 represent Track index
    track = command;
    sendNote(track, value);
  }
  else if (command < 0x08)
  { // 4-7 represent CC message
    track = command - 0x04;
    if (ccEnabled)
      sendControlChange(track, value);
#ifdef DEBUG_MODE
    Serial.println("Control Change!");
#endif
  }
  else if (command < 0x0C)
  { // 8-11 represent PC message
    track = command - 0x08;
    if (value == 0x7F) // let's use the GUNSHOT!!! y-FF command!
    {
      if (realTimeEnabled)
        clockTap();
    }
    else
    {
      if (pcEnabled)
        sendProgramChange(track, value);
#ifdef DEBUG_MODE
      Serial.println("Program Change!");
#endif
    }
  }
  else if (command <= 0x0F)
  { // 12-15 not yet sure!
    track = command - 0x0C;
    // unknown! skip consume one value byte usually 0 or 127
  }
  else
  {
    return; // not supposed to happened!!
  }
  lastTrack = track;
}

void routeRealtime(byte command)
{
  if (!realTimeEnabled)
    return;

  midiEventPacket_t message;
  switch (command)
  {
  case 0x7D: // send start to USB MIDI
    message = {0xFA};
    sendMIDI(message);

#ifdef USE_MIDI_h
    MIDI.sendRealTime(midi::Start);
    Serial1.flush();
#endif
    clockReset();
#ifdef DEBUG_MODE
    Serial.println("Start");
#endif
    break;
  case 0x7E: // send stop to USB MIDI //todo avoid stop glitch
    message = {0xFC};
    sendMIDI(message);

#ifdef USE_MIDI_h
    MIDI.sendRealTime(midi::Stop);
    Serial1.flush();
#endif
    clockReset();
    noteStopAll();

#ifdef DEBUG_MODE
    Serial.println("Stop!");
#endif
    break;
  case 0x7F:
    // microboy byte reading clock!! ignore for now.. very missleading....
    break;
  default:
#ifdef DEBUG_MODE
    Serial.print("Unknown Realtime: ");
    Serial.print(command);
#endif
    break;
  }
}

// byte readIncomingByte()
// {
//   byte receivedByte = 0;
//   PORTF |= (1 << PF6); // making sure Gameboy Serial In is HIGH! explanation: docs/references/gb_link_serial_in.md
//   for (uint8_t i = 0; i < 8; i++)
//   {
//     PORTF |= (1 << PF7); // Set HIGH
//     delayMicroseconds(BIT_DELAY);

//     receivedByte = (receivedByte << 1) + ((PINF & (1 << PINF5)) ? 1 : 0); // Read a bit, and shift it into the byte
//     //if (i == 0 && receivedByte == 0) return 0x7F;

//     PORTF &= ~(1 << PF7); // Set LOW
//     delayMicroseconds(BIT_DELAY);
//   }
//   delayMicroseconds(MIDI_DELAY);
//   return receivedByte &= 0x7F; // Set the MSB range value to 0-127
// }

/* This one based on Arduinoboy version, it is more stable on higher tempo
// Arduinoboy (https://github.com/trash80/Arduinoboy)
// by Timothy Lamb @trash80
*/
byte readIncomingByte()
{
  byte incomingMidiByte;
  delayMicroseconds(BYTE_DELAY);
  PORTF &= ~(1 << PF7); // LOW CLOCK_PIN
  delayMicroseconds(BYTE_DELAY);
  PORTF |= (1 << PF7); // HIGH CLOCK_PIN
  delayMicroseconds(BIT_DELAY);
  if (((PINF & (1 << PINF5)) ? 1 : 0))
  {
    incomingMidiByte = 0;
    for (int i = 0; i != 7; i++)
    {
      PORTF &= ~(1 << PF7); // LOW CLOCK_PIN
      delayMicroseconds(BIT_DELAY);
      PORTF |= (1 << PF7); // HIGH CLOCK_PIN
      incomingMidiByte = (incomingMidiByte << 1) + ((PINF & (1 << PINF5)) ? 1 : 0);
    }
    return incomingMidiByte;
  }
  return 0x7F;
}

void readGameboy()
{
  // enable this for non-blocking read
  // uint64_t currentTime = micros();
  // if (currentTime - lastReadGameboy < MIDI_DELAY) return;

  byte value = readIncomingByte();
  lastReadGameboy = micros();

  if (isCommandWaiting)
  {
    routeMessage(commandWaiting, value);
    isCommandWaiting = false;

    experimentalCorrection = commandWaiting;
    commandWaiting = 0x00;
  }
  else if (value >= 0x7D)
  { // 125-127 realtime message
    routeRealtime(value);
  }
  else if (value >= 0x70)
  { // 112-124 command message
    isCommandWaiting = true;
    commandWaiting = value;
  }
  else
  { // 0 - 111 Hiccups!!! not supposed to happened!!
#ifdef DEBUG_MODE
    if (value == 0)
    {
      Serial.print("Hiccups! Off:");
    }
    else if (value > 0x0F)
    {
      Serial.print("Hiccups! Note:");
    }
    else
    {
      Serial.print("Hiccups! Command:");
    }
    Serial.println(value);
#endif
    // EXPERIMENTAL HICCUPS! CORRECTION!! LOL
    if (experimentalCorrection)
    { // use the last command
      routeMessage(experimentalCorrection, value);
      experimentalCorrection = 0x00;
    }
    else
    { // use the last track
      routeMessage(lastTrack + 0x70, value);
    }
  }
}

ISR(PCINT0_vect)
{
  bool pinState = PINB & (1 << PB5);
  if (lastControlState == HIGH && pinState == LOW)
  {
    if (digitalRead(ROTARY_DT))
    {
      velocity++;
    }
    else
    {
      velocity--;
    }
    velocity = constrain(velocity, 0, 127);
  }
  lastControlState = pinState;
}

void readControl()
{
  switchControlState = digitalRead(ROTARY_SW);
  if (switchControlState == LOW && !controlPressed)
  {
    velocity = 0;
    controlPressed = true;
  }

  if (switchControlState == HIGH)
  {
    controlPressed = false;
  }

  displayMain();
}

void flushSerial()
{
  Serial1.flush();
  MidiUSB.flush();
}

void displaySplash()
{
  display.clearDisplay();
  display.setCursor(0, 0);
  display.println(PRODUCT_NAME);
  display.setCursor(0, 10);
  display.println(VERSION);
  display.setCursor(0, 20);
  display.print(RUSAAKKMODS);
  display.display();
}

void displayMain()
{
  uint64_t currentTime = millis();
  if (currentTime - lastPrint >= 1000)
  { // update display every 1 second
    display.clearDisplay();
    display.setCursor(0, 0);
    display.print("PU1 [");
    display.print(String(outputChannel[0] < 10 ? "0" : "") + String(outputChannel[0]));
    display.print("] | PU2 [");
    display.print(String(outputChannel[1] < 10 ? "0" : "") + String(outputChannel[1]));
    display.println("]");
    display.setCursor(0, 10);
    display.print("WAV [");
    display.print(String(outputChannel[2] < 10 ? "0" : "") + String(outputChannel[2]));
    display.print("] | NOI [");
    display.print(String(outputChannel[3] < 10 ? "0" : "") + String(outputChannel[3]));
    display.println("]");
    display.setCursor(0, 20);
    display.print("VEL:");
    display.print(velocity);
    display.print(" BPM:");
    display.print(bpm);
    display.display();
    lastPrint = currentTime;
  }
}

void setup()
{
  // Initialize Pins
  pinMode(CLOCK_PIN, OUTPUT);
  pinMode(SI_PIN, INPUT);
  pinMode(SO_PIN, OUTPUT);
  pinMode(ROTARY_CLK, INPUT_PULLUP);
  pinMode(ROTARY_DT, INPUT);
  pinMode(ROTARY_SW, INPUT_PULLUP);

  PCICR |= (1 << PCIE0);   // Enable pin change interrupt for PCIE0 (Port B)
  PCMSK0 |= (1 << PCINT5); // Enable pin change interrupt for PB5 (PCINT5)

  // IMPORTANT! Gameboy Serial In must be HIGH explanation: docs/references/gb_link_serial_in.md
  digitalWrite(SO_PIN, HIGH);

#ifdef DEBUG_MODE
  Serial.begin(9600); // to serial monitor
#else
  Serial.begin(115200); // to to USB
#endif
  // Initialize MIDI Serial Communication
  Serial1.begin(31250);

#ifdef USE_MIDI_h
  MIDI.begin(MIDI_CHANNEL_OMNI);
#endif

  // Initialize I2C for OLED
  Wire.begin();
  display.begin(SSD1306_SWITCHCAPVCC, OLED_I2C_ADDRESS);
  display.setTextSize(1);
  display.setTextColor(SSD1306_WHITE);

  clockReset();
  flushSerial();

  displaySplash();
}

void loop()
{
  readControl();
  readGameboy();
  // clockMIDI();
}

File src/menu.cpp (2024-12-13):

#include <U8g2lib.h>
#include <avr/interrupt.h>

// Pin definitions
#define ENCODER_PIN_A 8  // PCINT5
#define ENCODER_PIN_B 9  // PCINT4
#define BUTTON_PIN 7
#define BACK_PIN 6

// Rotary encoder variables
volatile int encoderPosition = 0;
volatile int lastEncoderPosition = 0; // Track the last encoder position to ensure precise steps
volatile int encoderState = 0;
volatile int lastEncoderState = 0;

// Button flags
volatile bool buttonPressed = false;
volatile bool backPressed = false;
volatile bool comboPressed = false;
volatile bool adjustValueMode = false;

// OLED setup
U8G2_SSD1306_128X32_UNIVISION_F_HW_I2C u8g2(U8G2_R0, /* reset=*/ U8X8_PIN_NONE);

// Menu state
enum MenuState { MAIN_DISPLAY, MAIN_MENU, SUBMENU };
MenuState currentState = MAIN_DISPLAY;

// Menu navigation variables
int currentMenuIndex = 0;   // Current menu or submenu index
int currentSubmenuIndex = 0;
int submenuValue[6] = {50, 75, 100, 20, 40, 60};  // Example values for submenus

void setup() {
  pinMode(BUTTON_PIN, INPUT_PULLUP);
  pinMode(BACK_PIN, INPUT_PULLUP);
  pinMode(ENCODER_PIN_A, INPUT_PULLUP);
  pinMode(ENCODER_PIN_B, INPUT_PULLUP);

  u8g2.begin();

  // Configure PCINT for encoder
  PCICR |= (1 << PCIE0); // Enable PCINT for pins 8-13
  PCMSK0 |= (1 << PCINT5) | (1 << PCINT4); // Enable interrupts on pins 9 and 8

  sei(); // Enable global interrupts
}

void loop() {
  // Handle button presses
  if (digitalRead(BUTTON_PIN) == LOW && digitalRead(BACK_PIN) == LOW && !comboPressed) {
    comboPressed = true;
    if (currentState == SUBMENU) {
      currentState = MAIN_MENU;
    }
  } else if (digitalRead(BUTTON_PIN) == HIGH || digitalRead(BACK_PIN) == HIGH) {
    comboPressed = false;
  }

  if (digitalRead(BUTTON_PIN) == LOW && !buttonPressed) {
    buttonPressed = true;
    if (currentState == MAIN_DISPLAY) {
      currentState = MAIN_MENU;
    } else if (currentState == MAIN_MENU) {
      currentState = SUBMENU;
      currentSubmenuIndex = 0;
    }
  } else if (digitalRead(BUTTON_PIN) == HIGH && buttonPressed) {
    buttonPressed = false;
  }

  if (digitalRead(BACK_PIN) == LOW && !backPressed) {
    backPressed = true;
    if (currentState == MAIN_MENU) {
      currentState = MAIN_DISPLAY; // Return to Main Display
    } else if (currentState == SUBMENU && !adjustValueMode) {
      currentState = MAIN_MENU; // Return to Menu Navigation Mode
    }
  } else if (digitalRead(BACK_PIN) == HIGH && backPressed) {
    backPressed = false;
  }

  switch (currentState) {
    case MAIN_DISPLAY:
      displayMainScreen();
      break;

    case MAIN_MENU:
      navigateMenu();
      break;

    case SUBMENU:
      navigateSubmenu();
      break;
  }
}

// --- Interrupt Service Routines ---
ISR(PCINT0_vect) {
  // Read the encoder pins
  int MSB = digitalRead(ENCODER_PIN_A); // Most significant bit
  int LSB = digitalRead(ENCODER_PIN_B); // Least significant bit

  int encoded = (MSB << 1) | LSB; // Combine the two pin states
  if (encoded != lastEncoderState) {
    if ((lastEncoderState == 0b00 && encoded == 0b01) ||
        (lastEncoderState == 0b01 && encoded == 0b11) ||
        (lastEncoderState == 0b11 && encoded == 0b10) ||
        (lastEncoderState == 0b10 && encoded == 0b00)) {
      encoderPosition++;
    } else if ((lastEncoderState == 0b00 && encoded == 0b10) ||
               (lastEncoderState == 0b10 && encoded == 0b11) ||
               (lastEncoderState == 0b11 && encoded == 0b01) ||
               (lastEncoderState == 0b01 && encoded == 0b00)) {
      encoderPosition--;
    }
    lastEncoderState = encoded;

    // Handle precise navigation
    if (encoderPosition != lastEncoderPosition) {
      if (currentState == MAIN_MENU) {
        if (encoderPosition > lastEncoderPosition) {
          currentMenuIndex = (currentMenuIndex + 1) % 3; // Loop within range
        } else {
          currentMenuIndex = (currentMenuIndex - 1 + 3) % 3; // Loop within range
        }
      } else if (currentState == SUBMENU) {
        if (digitalRead(BUTTON_PIN) == LOW) { // If button is pressed
          if (encoderPosition > lastEncoderPosition) {
            submenuValue[currentMenuIndex * 3 + currentSubmenuIndex] = constrain(submenuValue[currentMenuIndex * 3 + currentSubmenuIndex] + 1, 0, 100);
          } else {
            submenuValue[currentMenuIndex * 3 + currentSubmenuIndex] = constrain(submenuValue[currentMenuIndex * 3 + currentSubmenuIndex] - 1, 0, 100);
          }
        } else {
          if (encoderPosition > lastEncoderPosition) {
            currentSubmenuIndex = (currentSubmenuIndex + 1) % 3; // Loop within range
          } else {
            currentSubmenuIndex = (currentSubmenuIndex - 1 + 3) % 3; // Loop within range
          }
        }
      }
      lastEncoderPosition = encoderPosition;
    }
  }
}

// --- Display Functions ---
void displayMainScreen() {
u8g2.clearBuffer();
u8g2.setFontMode(1);
u8g2.setBitmapMode(1);
u8g2.setFont(u8g2_font_profont10_tr);
u8g2.drawStr(8, 8, "PU1");
u8g2.drawStr(40, 8, "PU2");
u8g2.setFont(u8g2_font_profont17_tr);
u8g2.drawStr(-2, 24, "[01]");
u8g2.drawStr(62, 24, "[02]");
u8g2.setFont(u8g2_font_profont10_tr);
u8g2.drawStr(72, 8, "WAV");
u8g2.setFont(u8g2_font_profont17_tr);
u8g2.drawStr(30, 24, "[10]");
u8g2.setFont(u8g2_font_profont10_tr);
u8g2.drawStr(104, 8, "NOI");
u8g2.setFont(u8g2_font_profont17_tr);
u8g2.drawStr(94, 24, "[--]");
u8g2.drawBox(34, 2, 2, 6);
u8g2.drawBox(2, 2, 2, 6);
u8g2.drawBox(98, 2, 2, 6);
u8g2.drawBox(66, 2, 2, 6);
u8g2.setDrawColor(2);
u8g2.drawBox(33, 1, 29, 8);
u8g2.drawBox(1, 1, 29, 8);
u8g2.drawBox(65, 1, 29, 8);
u8g2.drawBox(97, 1, 29, 8);
u8g2.sendBuffer();
}

void navigateMenu() {
  u8g2.clearBuffer();
  u8g2.setFont(u8g2_font_ncenB08_tr);
  u8g2.setCursor(0, 12);
  u8g2.print("Menu Item ");
  u8g2.print(currentMenuIndex + 1);
  u8g2.sendBuffer();
}

void navigateSubmenu() {
  u8g2.clearBuffer();
  u8g2.setFont(u8g2_font_ncenB08_tr);
  u8g2.setCursor(0, 12);
  u8g2.print("Submenu ");
  char indexLabel = 'A' + currentSubmenuIndex;
  u8g2.print(currentMenuIndex + 1);
  u8g2.print('.');
  u8g2.print(indexLabel);
  u8g2.print(": ");
  u8g2.print(submenuValue[currentMenuIndex * 3 + currentSubmenuIndex]);
  u8g2.sendBuffer();
}

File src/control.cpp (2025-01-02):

#include "control.h"
#include "display.h"
#include "midi_controller.h"
#include <avr/interrupt.h>

// Rotary encoder variables
volatile int encoderPosition = 0;
volatile int lastEncoderPosition = 0; // Track the last encoder position to ensure precise steps
volatile int encoderState = 0;
volatile int lastEncoderState = 0;

// Button flags
bool buttonPressed = false;
bool clicked = false;
bool shiftPressed = false;
bool comboPressed = false;

void control_checkNavigator()
{
  bool shiftState = digitalRead(SHIFT_PIN) == LOW;
  bool buttonState = digitalRead(BUTTON_PIN) == LOW;

  shiftPressed = shiftState;
  buttonPressed = buttonState;

  if (shiftPressed && buttonPressed)
  {
    if (!comboPressed)
    {
      comboPressed = true;
      if (display.currentState == MAIN_DISPLAY)
      {
        Cursor cur = display.mainCursors[display.mainCursorIndex];
        switch (cur.trigger)
        {
          case SOLO:
            if (midiController.isSolo && (midiController.soloTrack == display.mainCursorIndex))
            {
              midiController.isSolo = false;
            }
            else
            {
              midiController.isSolo = true;
              midiController.soloTrack = display.mainCursorIndex;
            }
            display.updateFlag = true;
            break;
          case MUTE:
            midiController.isMute = !midiController.isMute;
            display.updateFlag = true;
            break;
          default:
            //ignore for now
            break;
        }
      }
      else if (display.currentState == MAIN_MENU)
      {
        display.currentState = MAIN_DISPLAY;
      }
      else if (display.currentState == SUBMENU)
      {
        display.currentState = MAIN_MENU;
      }
    }
  }
  else
  {
    comboPressed = false;
  }

  if (!shiftPressed || !buttonPressed)
  {
    if (!clicked && buttonPressed)
    {
      clicked = true;
      if (display.currentState == MAIN_DISPLAY)
      {
        display.currentState = MAIN_MENU;
      }
      else if (display.currentState == MAIN_MENU)
      {
        display.currentState = SUBMENU;
      } else if (display.currentState == SUBMENU)
      {
        SubMenu sub = display.mainMenus[display.menuIndex].subMenus[display.submenuIndex];
        switch (sub.type)
        {
          case SAVE_CONFIG:
            config_save();
            display.currentState = MAIN_DISPLAY;
            break;
          case LOAD_DEFAULT:
            config_default();
            display.currentState = MAIN_DISPLAY;
            break;
          default:
            break;
        }
      }
    }
    else if (!buttonPressed)
    {
      clicked = false;
    }
  }
}

ISR(PCINT0_vect)
{
  static unsigned long lastInterruptTime = 0; // For debouncing
  static int lastEncoded = 0;                 // To track previous state for smoother transitions
  static int noiseFilterCounter = 0;          // Filter for noise

  unsigned long interruptTime = millis();

  if (interruptTime - lastInterruptTime > 5)
  {                                       // Adjust debounce delay to 5ms
    int MSB = digitalRead(ENCODER_PIN_A); // Most significant bit
    int LSB = digitalRead(ENCODER_PIN_B); // Least significant bit

    int encoded = (MSB << 1) | LSB;         // Combine the two pin states
    int sum = (lastEncoded << 2) | encoded; // Create a unique value for transition

    switch (sum)
    {
    case 0b0001:
    case 0b0111:
    case 0b1110:
    case 0b1000:
      noiseFilterCounter++;
      if (noiseFilterCounter >= 2)
      { // Require multiple valid signals to register
        encoderPosition++;
        noiseFilterCounter = 0;
      }
      break;
    case 0b0010:
    case 0b1011:
    case 0b1101:
    case 0b0100:
      noiseFilterCounter++;
      if (noiseFilterCounter >= 2)
      { // Require multiple valid signals to register
        encoderPosition--;
        noiseFilterCounter = 0;
      }
      break;
    default:
      // Invalid or noisy transition, reset filter
      noiseFilterCounter = 0;
      break;
    }

    lastEncoded = encoded;
    lastInterruptTime = interruptTime;

    if (encoderPosition != lastEncoderPosition)
    {
      int delta = encoderPosition - lastEncoderPosition;
      map(delta, -1, 1, -1, 1);
      lastEncoderPosition = encoderPosition;

      switch (display.currentState)
      {
        case MAIN_DISPLAY:
          if (shiftPressed)
          {
            Cursor cur = display.mainCursors[display.mainCursorIndex];
            uint16_t chan;
            uint16_t vel;
            switch (cur.type)
            {
              case RANGE_1_16:
                chan = constrain(config.outputChannel[display.mainCursorIndex] + delta, 1, 16);
                if (chan != config.outputChannel[display.mainCursorIndex])
                {
                  config.outputChannel[display.mainCursorIndex] = chan;
                  display.updateFlag = true;
                }
                break;
              case RANGE_0_127:
                vel = constrain(config.velocity + delta, 0, 127);
                if (vel != config.velocity)
                {
                  config.velocity = vel;
                  display.updateFlag = true;
                }
                break;
              default:
                //ignore for now
                break;
            }
          }
          else
          {
            display.mainCursorIndex = constrain(display.mainCursorIndex + delta, 0, display.cursorSize - 1);
          }
          break;
        case MAIN_MENU:
          display.menuIndex = constrain(display.menuIndex + delta, 0, display.mainMenuSize - 1);
          break;
        case SUBMENU:
          if (shiftPressed)
          {
            SubMenu sub = display.mainMenus[display.menuIndex].subMenus[display.submenuIndex];
            uint16_t value;
            switch (sub.type)
            {
              case ON_OFF:
                value = *sub.value == 0 ? 1 : 0;
                break;
              case RANGE_1_16:
                value = constrain(*sub.value + delta, 1, 16);
                break;
              case RANGE_0_127:
                value = constrain(*sub.value + delta, 0, 127);
                break;
              case RANGE_1000_5000_BY_100:
                value = constrain(*sub.value + delta * 100, 1000, 5000);
                break;
              default: //ignore for now
                break;
            }
            if (value != *sub.value)
            {
              *sub.value = value;
              display.updateFlag = true;  
            }
          }
          else
          {
            display.submenuIndex = constrain(display.submenuIndex + delta, 0, display.mainMenus[display.menuIndex].size - 1);
          }
          break;
      }
    }
  }
}
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

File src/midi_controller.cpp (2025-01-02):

#include <Arduino.h>
#include "midi_controller.h"
#include <MIDIUSB.h>

MIDIController midiController;

#ifdef USE_MIDI_h
// MIDI Library for MIDI Serial Communication supposed to be faster but unstable
#include <MIDI.h>
MIDI_CREATE_INSTANCE(HardwareSerial, Serial1, MIDI);
#else
HardwareSerial &MIDI = Serial1;
#endif

// track 0-PU1, 1-PU2, 2-WAV, 3-NOI
byte lastNote[4];
bool stopFlag;
bool startFlag;
uint64_t idleTime;
byte lastTrack;

bool midi_isTrackMuted(byte track)
{
    switch (track)
    {
    case 0:
        return midiController.isPU1Muted;
    case 1:
        return midiController.isPU2Muted;
    case 2:
        return midiController.isWAVMuted;
    case 3:
        return midiController.isNOIMuted;
    default:
        return false;
    }
}

void midi_flush()
{
    MidiUSB.flush();

#ifdef USE_MIDI_h
    MIDI.read();
#else
    Serial1.flush();
#endif
}

void midi_send(midiEventPacket_t message)
{
    MidiUSB.sendMIDI(message);

#ifndef USE_MIDI_h // NOT USE MIDI.h
    Serial1.write(message.byte1);
    Serial1.write(message.byte2);
    Serial1.write(message.byte3);
#endif

    midi_flush();
}

void midi_sendTick()
{
#ifdef USE_MIDI_h
    MIDI.sendRealTime(midi::Clock);
#endif
    midi_send({0x0F, 0xF8, 0x00, 0x00});
}

void midi_noteOff(byte track)
{
    byte note = lastNote[track];
    if (note)
    {
#ifdef USE_MIDI_h
        MIDI.sendNoteOff(note, 0x00, config.outputChannel[track]);
#endif

        midi_send({0x08, static_cast<uint8_t>(0x80 | (config.outputChannel[track] - 1)), note, 0x00});

        lastNote[track] = 0;
    }
}

void midi_noteOn(byte track, byte note)
{
    midi_noteOff(track); // stop previous note consider each track is monophonics

    if ((midiController.isSolo && track != midiController.soloTrack) || midiController.isMute) {
        return;
    }

#ifdef USE_MIDI_h
    MIDI.sendNoteOn(note, midiController.velocity, config.outputChannel[track]);
#endif

    midi_send({0x09, static_cast<uint8_t>(0x90 | (config.outputChannel[track] - 1)), note, (byte)config.velocity});

    lastNote[track] = note;
}

void midi_noteStop()
{
    for (uint8_t track = 0; track < 4; track++)
    {
        midi_noteOff(track);
    }
}

void midi_sendNote(byte track, byte note)
{
    if (note)
    { // value > 0 then its a "Note On" 1-127 | LSDJ note range 0-119
        midi_noteOn(track, note);
    }
    else
    { // value 0 then its a "Note Off"
        midi_noteOff(track);
    }
}

void midi_sendControlChange(byte track, byte value)
{
    byte ccNumber = 1; // Use the first CC number for Mode 0
    byte ccValue = value; 

#ifdef USE_MIDI_h
    MIDI.sendControlChange(ccNumber, ccValue, config.outputChannel[track]);
#endif

    midi_send({0x0B, static_cast<uint8_t>(0xB0 | (config.outputChannel[track] - 1)), ccNumber, ccValue});

#ifdef DEBUG_MODE
    Serial.print("CC Command - track:");
    Serial.print(track);
    Serial.print(" value:");
    Serial.println(value);
#endif
}

void midi_sendProgramChange(byte track, byte value)
{
#ifdef USE_MIDI_h
    MIDI.sendProgramChange(value, config.outputChannel[track]);
#endif

    midi_send({0x0C, static_cast<uint8_t>(0xC0 | (config.outputChannel[track] - 1)), value, 0x00});

#ifdef DEBUG_MODE
    Serial.print("PC Command - track:");
    Serial.print(track);
    Serial.print(" value:");
    Serial.println(value);
#endif
}

void midi_experimentalCorrection(byte value)
{
    // EXPERIMENTAL HICCUPS! CORRECTION!! LOL
    if (value > 0)
    {
#ifdef DEBUG_MODE
        Serial.print("Hiccups!!: ");
        Serial.println(value);
#endif
        midi_sendNote(lastTrack, value);
    }
}
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

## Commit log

2024-11-15 swap pin to gameboy ports, was mixed in to gb out, out to gb in
2024-11-15 add schematics project
    [megaboy_midi.kicad_pcb, megaboy_midi.kicad_sch]
2024-11-19 microout working 1st time still need improvement glitching probably race condition
    [megaboy_midi.kicad_sch]
2024-11-19 microboy fixed race condition
    [microboy.ino]
2024-11-20 test BPM knob, resolution issue need to eliminate delay
    [microboy.ino]
2024-11-20 use macro port register to read and write greatly reduced delay, but intermitten glitches still appearing not too frequent but still annoying. need to remove the delay completely, millis & micros doe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
    [microboy.ino]
2024-11-21 experimental correction on byte reading
    [microboy.ino]
2024-11-22 move to port B, but glitch is worsen maybe because the CC and PC
    [microboy.ino]
2024-11-23 stable able using Arduinoboy reading method
2024-11-24 forgot to mention on previous commit ive enabled rotary encoder
2024-11-28 crashes somehow, yesterday was fine T_T
    [control.cpp, main.cpp, midi_controller.cpp]
2024-12-09 bugs in rotary need fixing
    [control.cpp, control.h, midi_controller.cpp]
2024-12-09 enable mute switch
2024-12-10 rotary encoder triggered itself
2025-01-02 fix velocity
